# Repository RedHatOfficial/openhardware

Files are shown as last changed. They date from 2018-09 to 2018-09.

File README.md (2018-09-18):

# openhardware

This repository contains the sources for Red Hat's "blinky" hardware giveaway for the Open Hardware Summit 2018.

Board files (.brd/.sch) are under the CERN Open Hardware License v1.2, except for some libraries embedded from SparkFun, which are under the 
CC-BY-SA license.

Source code (.ino) is GPLv2 or later.

All documentation is under the CC-BY-SA license.

Red Hat, and the Shadowman logo are registered trademarks of Red Hat, Inc, and no special permission is granted to use these marks as part of 
this licensing.

Thanks to Alicia Gibb and Nathan Seidle for creating this awesome kit!

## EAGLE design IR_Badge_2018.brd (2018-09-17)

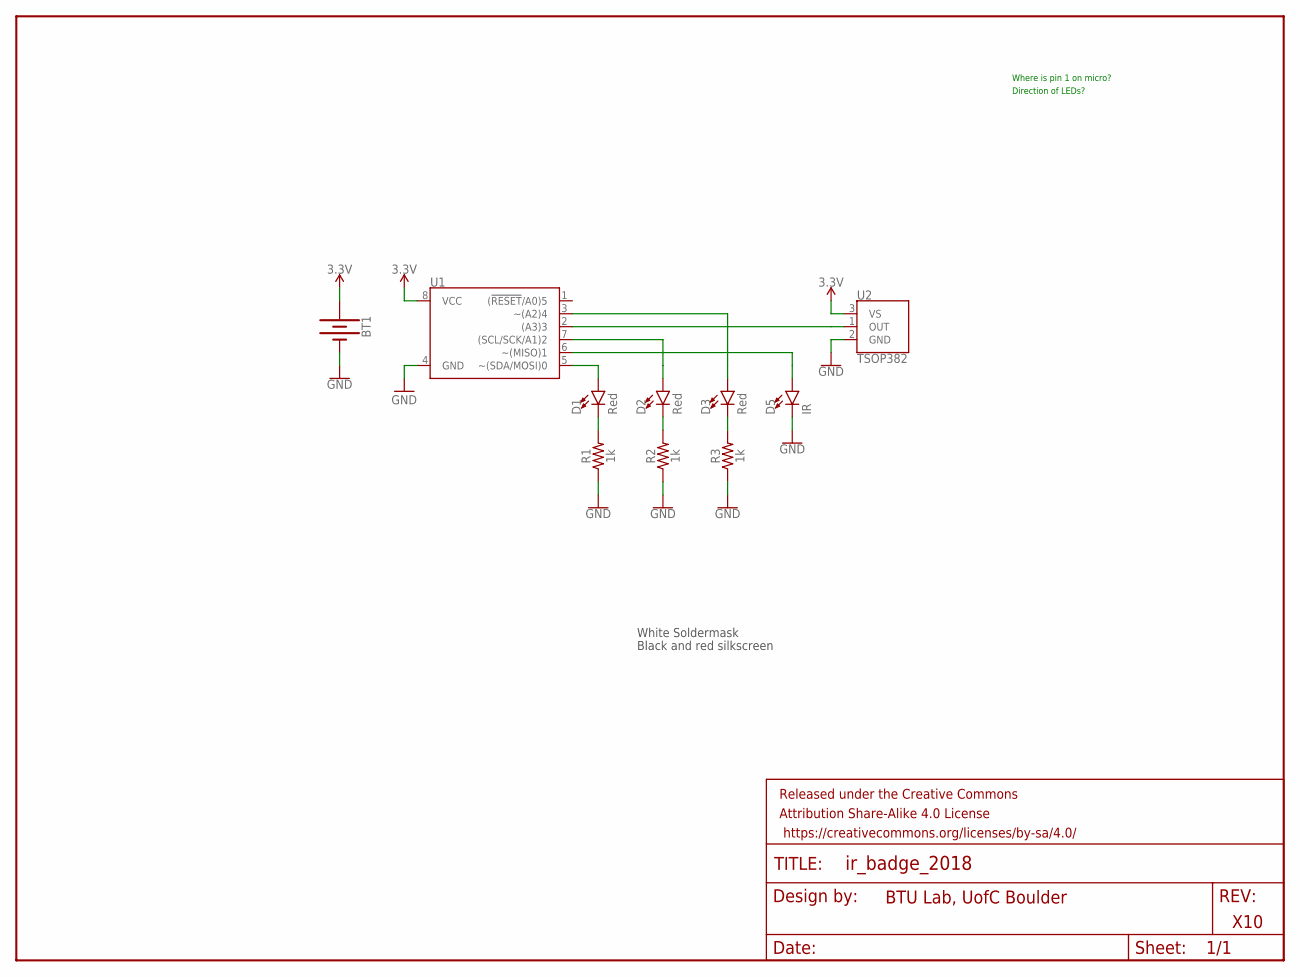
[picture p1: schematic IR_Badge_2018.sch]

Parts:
BT1: BATTERY-20MM_PTH; BATTCOM_20MM_PTH
D1, D2, D3: Red; LED_5MM_EXTRASILK
D5: IR; LED_5MM_NOSILK
FRAME1: FRAME-LETTER; CREATIVE_COMMONS
R1, R2, R3: 1k; RESISTOR
U1: ATTINY85-ARDUINODIP; DIP-8
U2: TSOP382; TSOP382-HORIZONTAL

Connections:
3.3V: BT1.1 (+), U1.8 (VCC), U2.3 (VS)
GND: BT1.2 (-), D5.K (C), R1.P$1 (1), R2.P$1 (1), R3.P$1 (1), U1.4 (GND), U2.2 (GND)
unnamed: D1.A, U1.5 (~(SDA/MOSI)0)
unnamed: D2.A, U1.7 ((SCL/SCK/A1)2)
unnamed: D1.K (C), R1.P$2 (2)
unnamed: D3.A, U1.3 (~(A2)4)
unnamed: D2.K (C), R2.P$2 (2)
unnamed: D3.K (C), R3.P$2 (2)
unnamed: D5.A, U1.6 (~(MISO)1)
unnamed: U1.2 ((A3)3), U2.1 (OUT)

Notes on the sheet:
X10
BTU Lab, UofC Boulder
White Soldermask
Black and red silkscreen
Where is pin 1 on micro?
Direction of LEDs?

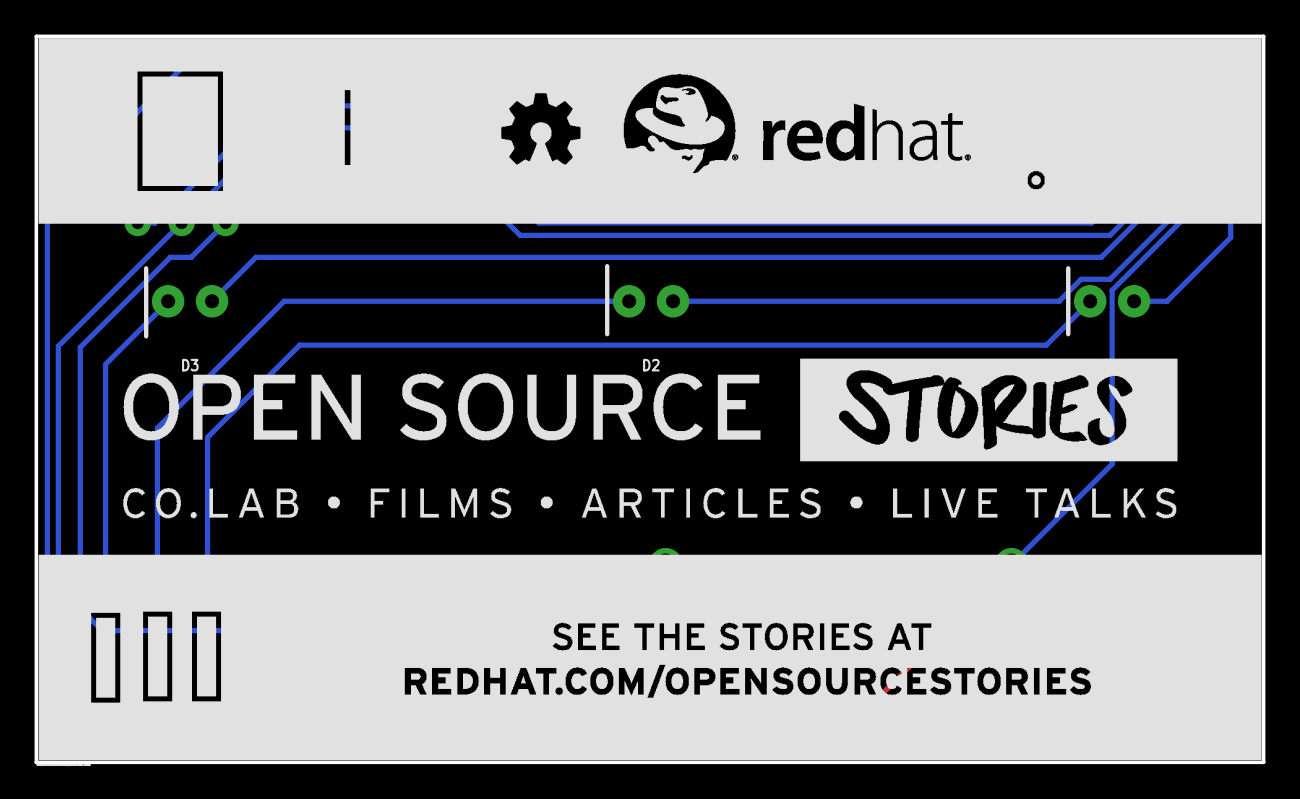
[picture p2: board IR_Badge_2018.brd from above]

Board: 2 copper layers, 71.0 x 42.0 mm, 11 parts (1 on the bottom side), 10 nets.

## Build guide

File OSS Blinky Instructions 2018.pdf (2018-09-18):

How to make your own Red Hat Open Source Stories blinky

- Include Red Hat logo
- https://github.com/RedHatOfficial/openhardware
Step 1: Bend and solder in the resistors by touching solder and the component to a soldering iron.

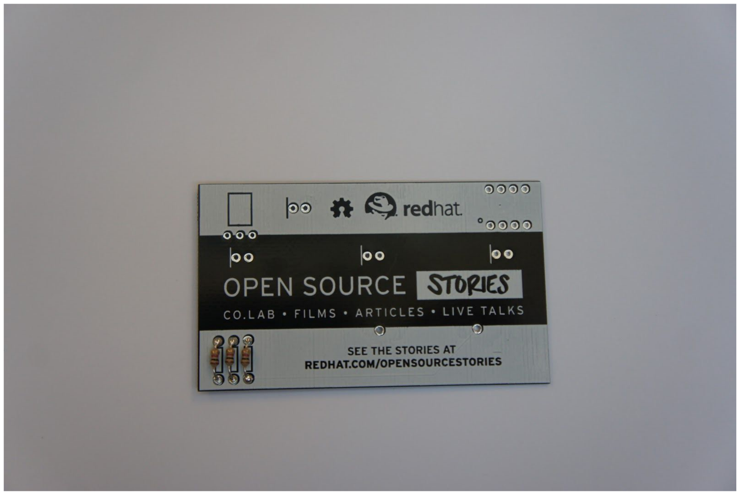
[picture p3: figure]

Step 2: Bend and solder in the IR sensor. The half circle should face forward.

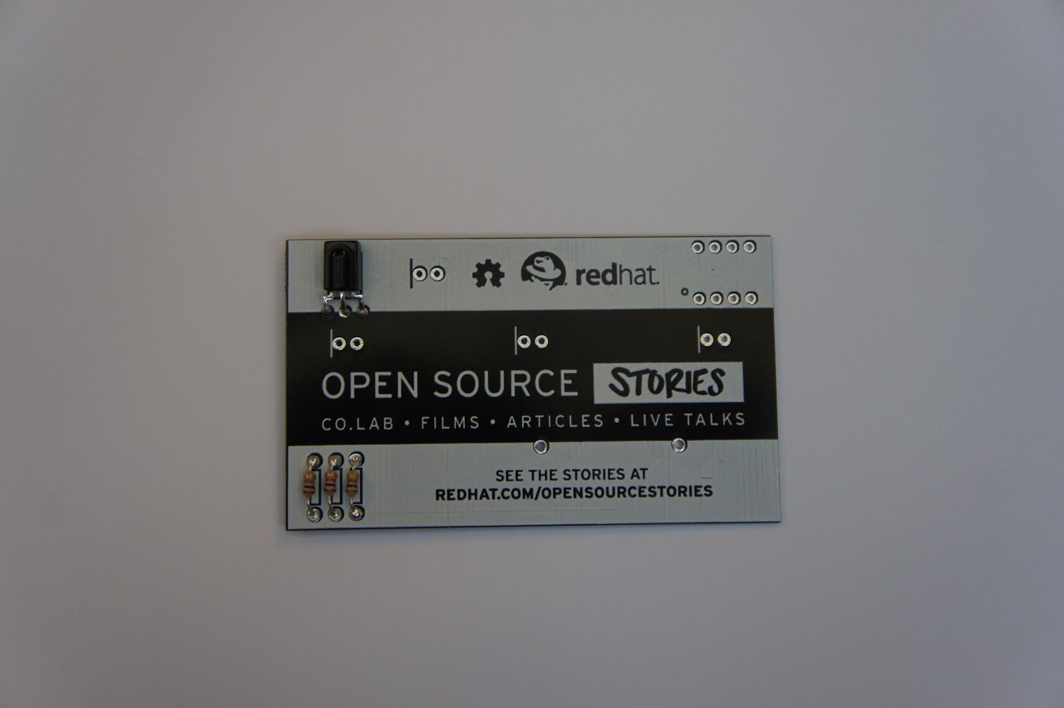
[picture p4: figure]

S

t

e

p

3: S

old

e

r in

y

o

u

r

c

hip. M

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
hip is lo

c

a

t

e

d in

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
r is

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
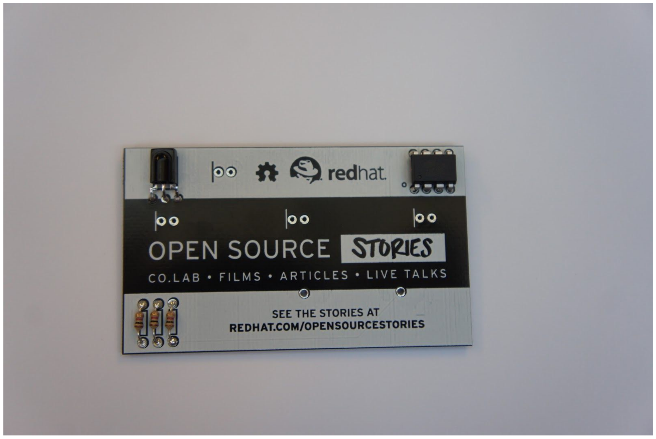
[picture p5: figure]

Step 4: Solder in your red and IR LEDs. Remember! LEDs are directional - match the short leg / flat side with the vertical line.

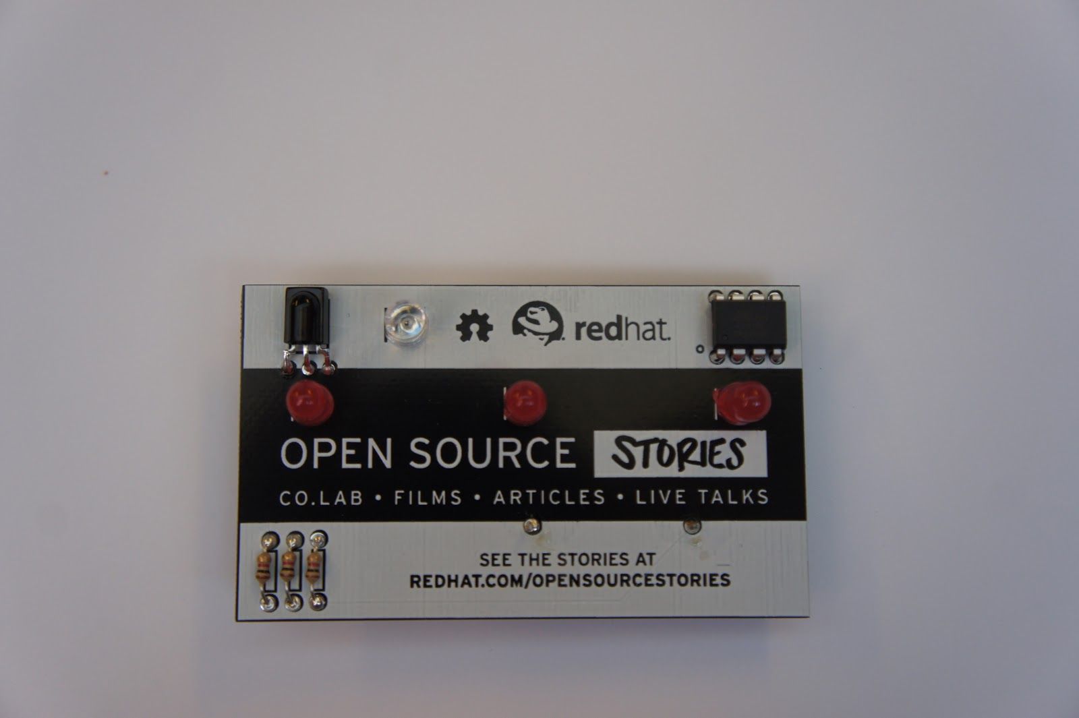
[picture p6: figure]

Step 5: Solder your battery holder on the back side of the board.

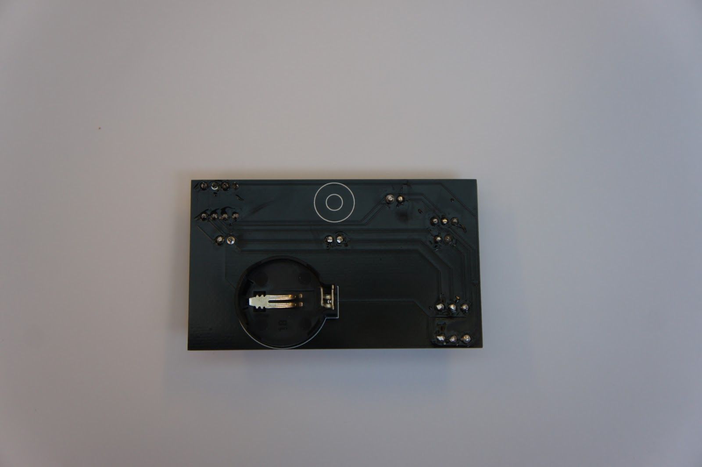
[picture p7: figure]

Step 6: Put your battery in the holder + side up.

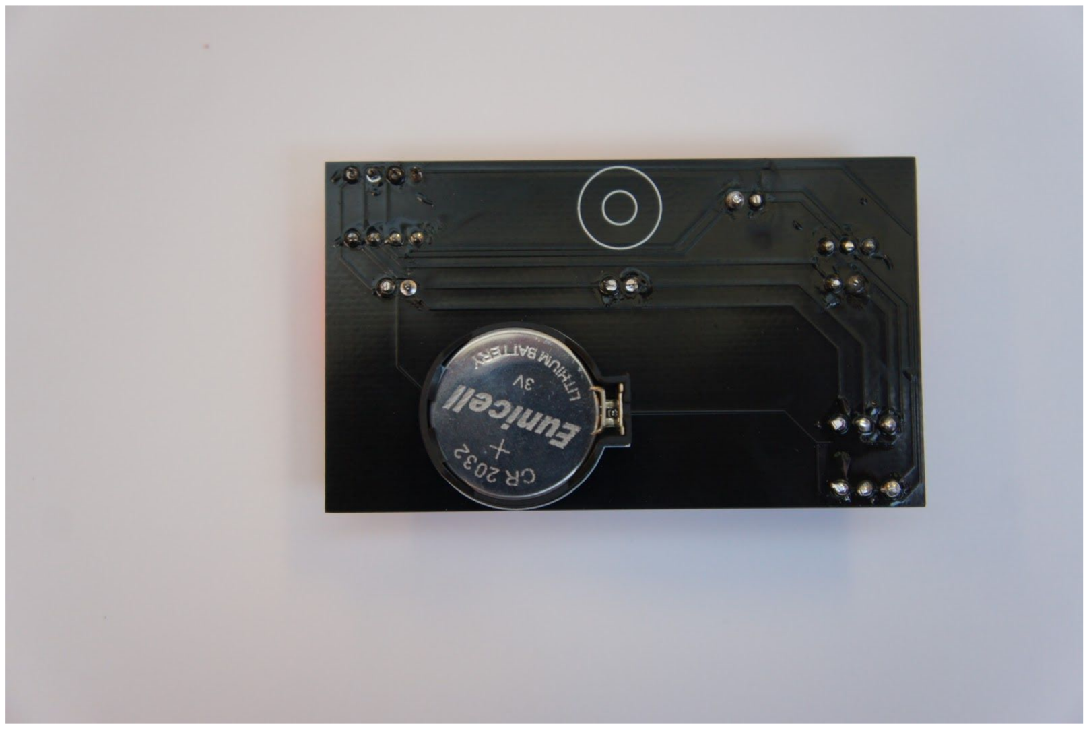
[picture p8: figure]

Step 7: Attach the magnet and put it on your lanyard, shirt or backpack!

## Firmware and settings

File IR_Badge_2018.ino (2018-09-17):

/*
   Red Hat Badge 2018 - Now with blinking!
   Badge turns on all 3 LEDs. If another badge is detected, begin flashing.
   August 5th, 2018
   By Alicia Gibb @ Lunchbox Electronics and Nathan Seidle @ SparkFun Electronics
   
   Once assembled a badge is on all the time, but if it sees another badge
   both badges start the blinky dance!
   
   9mA average current with 1ks on the red LEDs. CR2032 = roughly 220mAh.
   So should last for 20+ hours

   IR libraries are too big and/or break delay() or other timers. So we bit bang 
   the IR transmission.
*/

const byte LED1 = 0;
const byte IRLED = 1;
const byte RECV_PIN = 3;
const byte LED2 = 2;
const byte LED3 = 4;

#define MODE_SPARKLE 1
#define MODE_ON 2

byte currentMode = MODE_ON;
byte loopCounter = 0; //Counts the number of times we do the main loop. Assume it's 1s per loop

void setup()
{
  pinMode(LED1, OUTPUT);
  pinMode(LED2, OUTPUT);
  pinMode(LED3, OUTPUT);
  pinMode(IRLED, OUTPUT);
  pinMode(RECV_PIN, INPUT_PULLUP);

  bootHello(); //Blink a certain way at startup
  
  loopCounter = 0;
  currentMode = MODE_ON;
}

void loop() {

  //Depending on the mode, make the LEDs dance
  if (currentMode == MODE_SPARKLE)
    blinkHappyDance();
  else
    turnLEDsOn();

  //If we have no more IR from another badge for 3s, then go to standby/always on mode
  if (loopCounter++ > 3)
  {
    currentMode = MODE_ON;
    loopCounter = 4; //Force a non-overflow
  }

  delay(5); //Without a delay the RX will detect itself

  //If we detect any IR code then sparkle the LEDs!
  //Scan for max of 500ms
  for (byte x = 0 ; x < 5 ; x++)
  {
    if (irIncoming() == true)
    {
      currentMode = MODE_SPARKLE;
      loopCounter = 0; //Reset the loop/timeout
      break; //We have something! Leave the while loop
    }
  }

  //Blink the IR LED to announce our existance
  sendIR(0xAA);
  delay(5); //Without a delay the RX will detect itself
}

//Blink LEDs in chasing pattern
void blinkHappyDance()
{
  digitalWrite(LED1, LOW);
  digitalWrite(LED2, LOW);
  digitalWrite(LED3, LOW);

  byte chaseDelay = 50;

  for (byte x = 0 ; x < 3 ; x++)
  {
    digitalWrite(LED1, HIGH);
    delay(chaseDelay);
    digitalWrite(LED1, LOW);

    digitalWrite(LED2, HIGH);
    delay(chaseDelay);
    digitalWrite(LED2, LOW);

    digitalWrite(LED3, HIGH);
    delay(chaseDelay);
    digitalWrite(LED3, LOW);

    //While we're dancing, blink IR LED to let the world know of our existance
    sendIR(0xAA);
  }
}

//Blink LEDs fast and simultaneously
void bootHello()
{
  byte chaseDelay = 50;

  for (byte x = 0 ; x < 3 ; x++)
  {
    digitalWrite(LED1, HIGH);
    digitalWrite(LED2, HIGH);
    digitalWrite(LED3, HIGH);
    delay(chaseDelay);
    digitalWrite(LED1, LOW);
    digitalWrite(LED2, LOW);
    digitalWrite(LED3, LOW);
  }
}

//Turn the 3 LEDs on - this is the normal mode when no other badge is present
void turnLEDsOn()
{
  digitalWrite(LED1, HIGH);
  digitalWrite(LED2, HIGH);
  digitalWrite(LED3, HIGH);
}

//Checks to see if a character is coming in
//For 100ms, look for receiver to go low
boolean irIncoming()
{
  int counter = 0;
  while (1)
  {
    if (counter++ == 100) return (false);
    if (digitalRead(RECV_PIN) == LOW) return (true); //We see something!
    delay(1);
  }
}

//Sends a thing at 32kHz = 31.25ms per pulse
//At 8*8*10 = 6400, the receiver sees a 0 with low of 17.1ms
void sendIR(byte thingToSend)
{
  for (int x = 0 ; x < 8 * 8 * 10 ; x++)
  {
    digitalWrite(IRLED, HIGH);
    __asm__("nop\n\t");
    digitalWrite(IRLED, LOW);
    __asm__("nop\n\t");
  }
}

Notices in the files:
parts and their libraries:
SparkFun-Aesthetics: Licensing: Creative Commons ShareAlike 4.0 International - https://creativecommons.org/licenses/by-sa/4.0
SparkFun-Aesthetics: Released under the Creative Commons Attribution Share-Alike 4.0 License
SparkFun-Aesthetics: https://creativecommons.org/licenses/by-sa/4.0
